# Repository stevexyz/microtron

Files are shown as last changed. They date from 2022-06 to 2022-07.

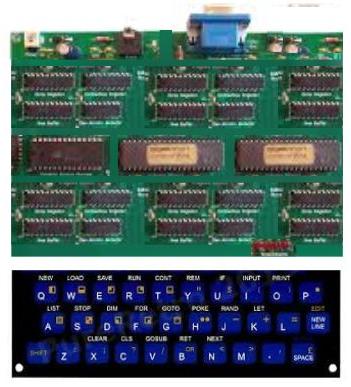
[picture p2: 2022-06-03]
microtron/microtron.jpg

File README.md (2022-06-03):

This is a fork of gigatron that is trying to minimize even more the number of components required.

Original project by Marcel van Kervinck and Walter Belgers can be found at https://gigatron.io

Discussion about microtron can be found at https://forum.gigatron.io/viewtopic.php?t=255

Schematic files are edited with KiCAD 6.

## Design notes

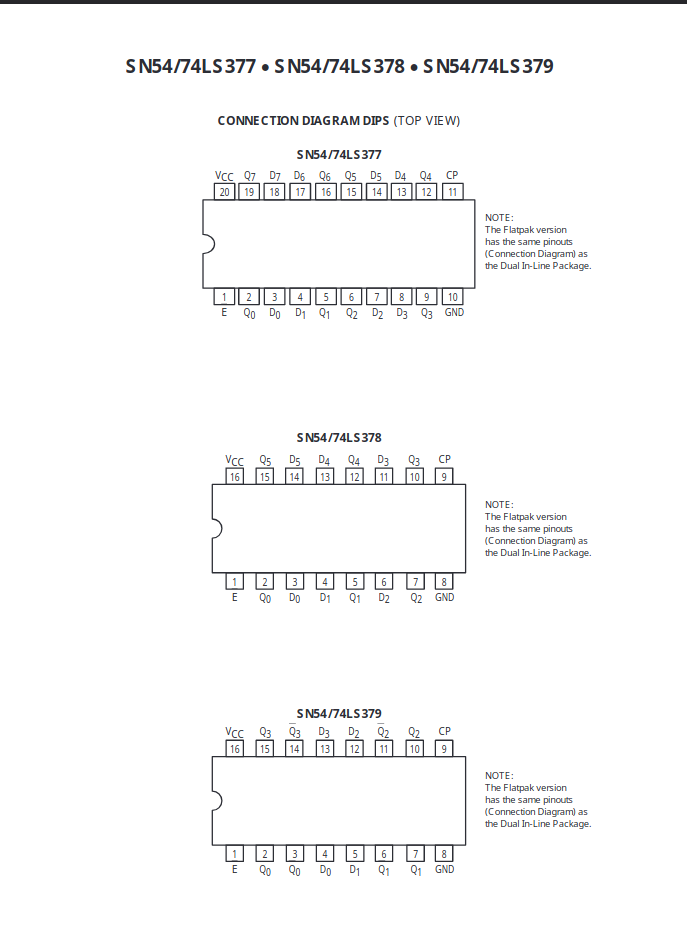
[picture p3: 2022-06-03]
datasheets/74ls377 8bit FF b.png

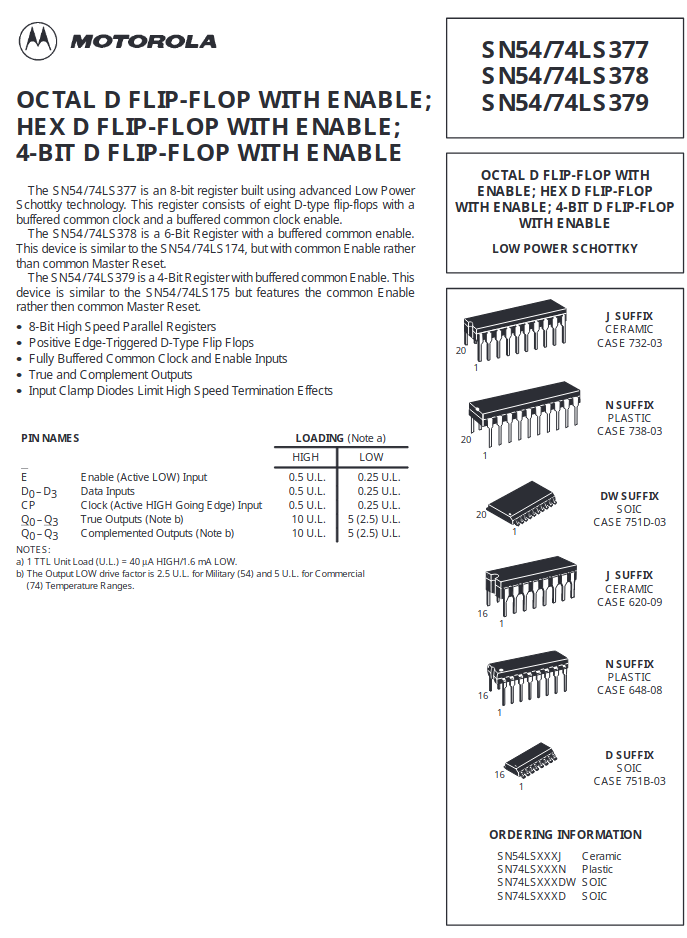
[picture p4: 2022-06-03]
datasheets/74ls377 8bit FF a.png

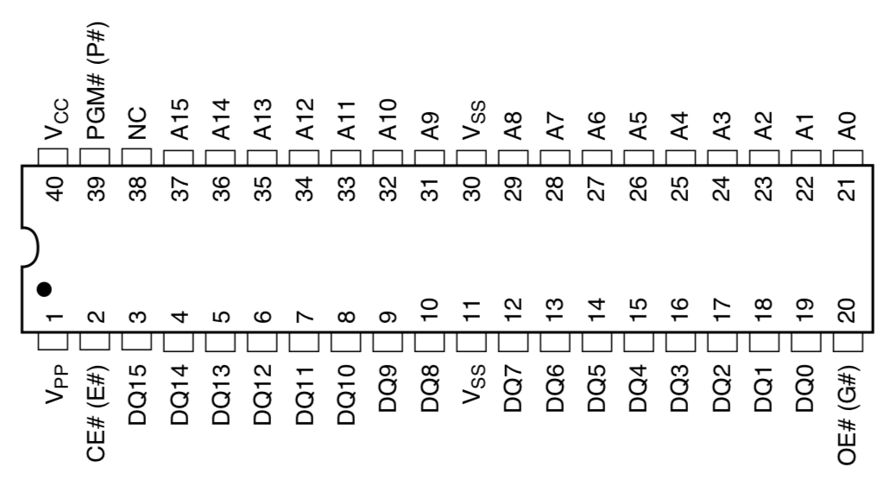
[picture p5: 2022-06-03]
datasheets/27c1024.png

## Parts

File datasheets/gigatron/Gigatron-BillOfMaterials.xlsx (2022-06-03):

Gigatron Bill of Materials
https://gigatron.io/
Copyright © 2020 Walter Belgers
This Gigatron Bill of Materials is provided "as-is"
and licensed under CC BY-SA 4.0.
To view a copy of this license, visit
https://creativecommons.org/licenses/by-sa/4.0
 |  |  |  |  |  | TTL microcomputer
Function/module | Description | Part/value | On PCB | Per kit | Part URL (e.g.)
Clock | 47pF ceramic disc capacitor, radial | Code 47 | C1-C3 | 3 | https://www.digikey.nl/product-detail/en/vishay-bc-components/K470J15C0GF5TL2/BC1009CT-ND/286631
Power | 220uF polarized radial input cap | Panasonic EEU-FC1E221 | C4 | 1 | https://nl.farnell.com/panasonic/eeu-fc1e221/cap-220-f-25v-20/dp/9692142
Power, Audio | 100nF ceramic disc | Code 104 | C5-C44 | 40 | https://www.digikey.nl/product-detail/en/vishay-bc-components/K104K10X7RF5UH5/BC2665CT-ND/2356879
Power | Zener diode 5.6V/5W | 1N5339B, DO-15 | D1 | 1 | https://nl.mouser.com/ProductDetail/Micro-Commercial-Components-MCC/1N5339B-TP
Power, Blinkenlights | LED (red) | 1.8V, 2mA, 3.15mm | D2, D5-D8 | 5 | https://www.digikey.com/product-detail/en/everlight-electronics-co-ltd/HLMP1700C6A0/1080-1048-1-ND/2675539
Control unit | Signaling diode | 1N60P or BAT42 compatible, DO-35 | D3-D4,D9-D36 | 30 | https://nl.mouser.com/ProductDetail/Vishay-Semiconductors/BAT42-TR
Power | Multifuse 60V/0.75A/180mΩ | MF-R075-ND | F1 | 1 | https://www.digikey.nl/product-detail/en/bourns-inc/MF-R075/MF-R075-ND/259967
Power | Mini-USB receptacle | 54819-0519 | J1 | 1 | http://nl.farnell.com/molex/54819-0519/mini-usb-2-0-otg-type-b-rcpt-th/dp/9786465
Audio | 3.5 mm audio jack | SJ-352{345}N | J2 | 1 | https://www.digikey.nl/product-detail/en/cui-inc/SJ1-3523N/CP1-3523N-ND/738689
Video | 15pin D-SUB female receptacle | L77HDE15SD1CH4R | J3 | 1 | http://uk.farnell.com/amphenol/l77hde15sd1ch4r/connector-hd-d-sub-rcpt-15pos/dp/2401183?MER=sy-me-pd-mi-alte
Game controller | 9pin D-SUB male receptacle | 5747840-3 | J4 | 1 | https://www.digikey.nl/product-detail/en/te-connectivity-amp-connectors/5747840-3/A32091-ND/808646
Clock | Feedback resistor | 1M | R1 | 1 | https://www.digikey.nl/product-detail/en/stackpole-electronics-inc/CF14JT1M00/CF14JT1M00CT-ND/1830423
Clock | Damping resistor | 1k | R2 | 1 | https://www.digikey.nl/product-detail/en/stackpole-electronics-inc/CF14JT1K00/CF14JT1K00CT-ND/1830350
Power, Control unit, Audio, Input | Resistor 2.2kΩ | 2.2k | R3,R6-R7,R10,R19 | 5 | https://www.digikey.nl/product-detail/en/stackpole-electronics-inc/CF14JT2K20/CF14JT2K20CT-ND/1830358
Controll unit, Blinkenlights | 5-pin resistor array, 2.2kΩ | 4605X-101-222LF | R4-R5,R8 | 3 | https://nl.mouser.com/ProductDetail/Bourns/4605X-101-222LF
Audio | 6-pin R2R netwerk, 10kΩ | 4606X-R2R-103LF | R9 | 1 | https://nl.mouser.com/ProductDetail/Bourns/4606X-R2R-103LF/
Video | DAC resistor | 1.5k | R11,R13,R15 | 3 | https://www.digikey.nl/product-detail/en/stackpole-electronics-inc/CF14JT1K50/CF14JT1K50CT-ND/1830354
Video | DAC resistor | 750 | R12,R14,R16 | 3 | https://www.digikey.nl/product-detail/en/stackpole-electronics-inc/CF14JT750R/CF14JT750RCT-ND/1830347
Video | Terminator HS/VS lines | 68 | R17-R18 | 2 | https://www.digikey.nl/product-detail/en/stackpole-electronics-inc/CF14JT68R0/CF14JT68R0CT-ND/1830323
Clock | Hex inverter (74HCT) | 74HCT04 | U1 | 1 | http://eu.mouser.com/ProductDetail/Texas-Instruments/SN74HCT04N/
Power | Supervisory circuit. Power-on Reset | MCP100-450DI/TO | U2 | 1 | https://www.digikey.nl/products/en?keywords=MCP100-450DI
Program Counter, X register | 4-bit presettable counter '161/'163 | 74HCT161 | U3-U6,U29-U30 | 6 | https://nl.mouser.com/Search/ProductDetail.aspx
Program ROM | EPROM 1Mb (64Kx16) | 27C1024, ≤150ns | U7 | 1 | https://nl.mouser.com/ProductDetail/Microchip-Technology-Atmel/AT27C1024-70PU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
IR,D,XOUT registers | 8-bit D-type register | 74HCT273 | U8-U9,U38 | 3 | https://nl.mouser.com/ProductDetail/Texas-Instruments/SN74HCT273N/
Databus en input | Octal bus driver non-inv | 74HCT244 | U10,U28 | 2 | https://nl.mouser.com/ProductDetail/Texas-Instruments/SN74HCT244N
Control unit | Dual 2-to-4 decoder | 74HCT139 | U11 | 1 | https://nl.farnell.com/texas-instruments/sn74hct139n/logic-dual-2to4-decod-demux-16dip/dp/3119925
Control unit, ALU | Dual 4-to-1 multiplexer | 74HCT153 | U12,U17-U24 | 9 | https://nl.mouser.com/ProductDetail/Texas-Instruments/CD74HCT153E/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
Control unit | 3-to-8 decoder | 74HCT138 | U13-U14 | 2 | https://nl.farnell.com/texas-instruments/sn74hct138n/ic-decoder-demux/dp/3119923?ost=74HCT138
Control unit | Octal inverting buffer | 74HCT240 | U15 | 1 | https://nl.farnell.com/texas-instruments/sn74hct240n/octal-buffer-line-driver-74hct240/dp/3119513
Control unit | Quad 2-input OR | 74HCT32 | U16 | 1 | https://nl.mouser.com/ProductDetail/Texas-Instruments/CD74HCT32EE4
ALU | 4-bit adder | 74HCT283 | U25-U26 | 2 | https://nl.mouser.com/ProductDetail/Texas-Instruments/CD74HCT283E/
AC, OUT and Y registers | Octal D-type flip-flops with common enable | 74HCT377 | U27,U31,U37 | 3 | https://www.digikey.nl/product-detail/en/texas-instruments/SN74HCT377N/296-8417-5-ND/376829
Address unit | Quad 2-to-1 line data selector | 74HCT157 | U32-U35 | 4 | https://www.digikey.nl/product-detail/en/texas-instruments/SN74HCT157N/296-8397-5-ND/376831
Data RAM | SRAM 32k x 8, 55ns | 62256 | U36 | 1 | http://nl.farnell.com/lyontek/ly62256pl-55lli/sram-256k-32kx8-2-7-5-5v-28pdip/dp/2253656?ost=LY62256PL-55LLI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
Input register | 8-bit shift register with 3-state output | 74HC595 | U39 | 1 | http://eu.mouser.com/ProductDetail/Texas-Instruments/SN74HC595N/
Clock | 6.25MHz/30pF crystal | MP062-E | Y1 | 1 | http://eu.mouser.com/Search/ProductDetail.aspx?R=MP062-Evirtualkey67110000virtualkey774-MP062-E
Interconnect | Printed Circuit Board (PCB) | green, lead-free HASL | - | 1 | your favourite PCB manufacturer
Power | USB cable | AWG28 | - | 1 | https://nl.mouser.com/ProductDetail/562-3021055-03
Program ROM | UV protection label | 25.4mm x 10mm | - | 1 | https://uk.farnell.com/te-connectivity/12100/label-eprom-pcb-pk500/dp/463802
IC sockets | IC socket | 40-pin DIP | - | 1 | https://www.digikey.nl/product-detail/en/on-shore-technology-inc/ED40DT/ED3048-5-ND/4147604
IC sockets | IC socket | 28-pin DIP | - | 1 | https://www.digikey.nl/product-detail/en/assmann-wsw-components/AR-28-HZL-TT/AE10017-ND/821771
Game controller | Prefab gamepad, famicom clone | DB9 serial | - | 1 | https://nl.aliexpress.com/item/32819985527.html
Enclosure | Wooden casing with plexiglass |  | - | 1 | custom made, no longer available
Enclosure | Little rubber feet (bumpons) | SJ-5302 (7.9mm) | - | 8 | https://nl.mouser.com/ProductDetail/3M-Electronic-Specialty/SJ-5302-CLEAR?qs=sGAEpiMZZMvlOED0T0kTWjxHiH3P5SU9
Manual | Full-colour paper manual | Wire-O, plastic cover | - | 1 | local copy shop
Pluggy McPlugface | Printed Circuit Board (PCB) | green, lead-free HASL | - | 1 | your favourite PCB manufacturer
Pluggy McPlugface | PS/2 receptacle | mini-DIN 6 pins | J1 | 1 | https://nl.mouser.com/ProductDetail/Kycon/KMDGX-6S-AS
Pluggy McPlugface | 9pin D-SUB female receptacle | L77SDE09SOL2 | J2 | 1 | https://nl.mouser.com/ProductDetail/523-L77SDE09SOL2
Pluggy McPlugface | Microcontroller | ATtiny85 DIP-8 | U1 | 1 | http://www.mouser.com/ProductDetail/microchip/attiny85-20pu/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
Pluggy McPlugface | IC socket | 8-pin DIP | - | 1 | http://www.mouser.com/ProductDetail/mill-max/110-47-308-41-001000/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
EPROM content | https://github.com/kervinck/gigatron-rom
ATtiny content | https://github.com/kervinck/gigatron-rom/tree/master/Utils/BabelFish
Assembly manual | https://gigatron.io/manual
Main PCB design files | https://gigatron.io/pcb
Pluggy PCB design files | https://gigatron.io/pluggy
20200623

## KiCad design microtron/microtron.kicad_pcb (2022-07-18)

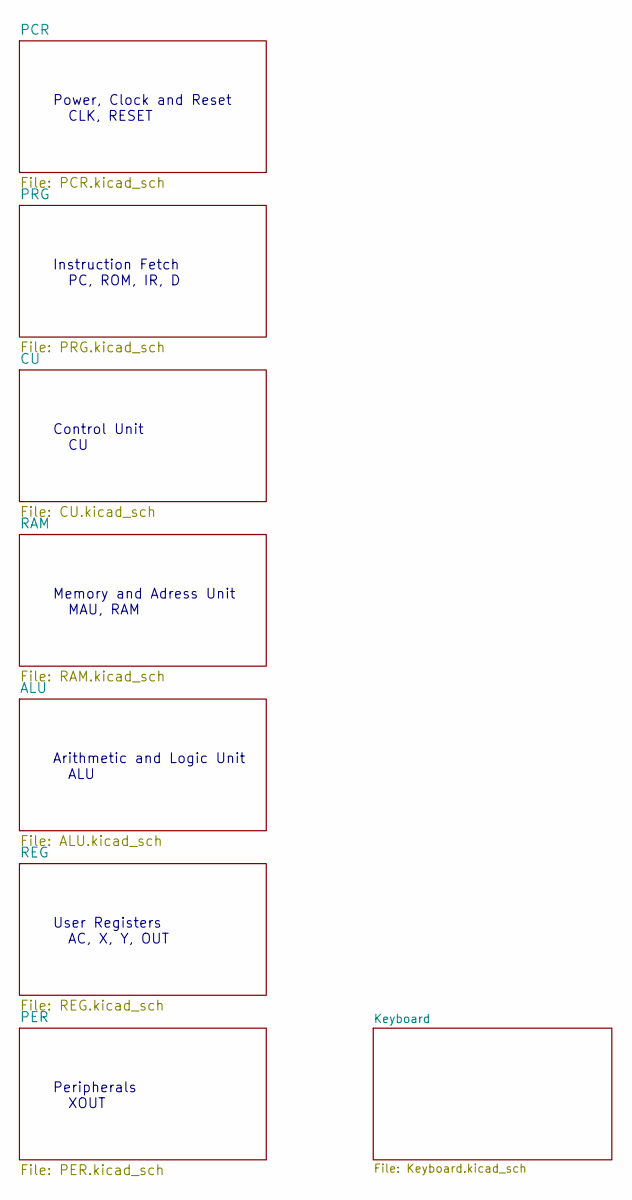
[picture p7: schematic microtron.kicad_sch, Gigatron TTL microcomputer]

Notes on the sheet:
Control Unit CU
Instruction Fetch PC, ROM, IR, D
Arithmetic and Logic Unit ALU
Memory and Adress Unit MAU, RAM
User Registers AC, X, Y, OUT
Peripherals XOUT
Power, Clock and Reset CLK, RESET

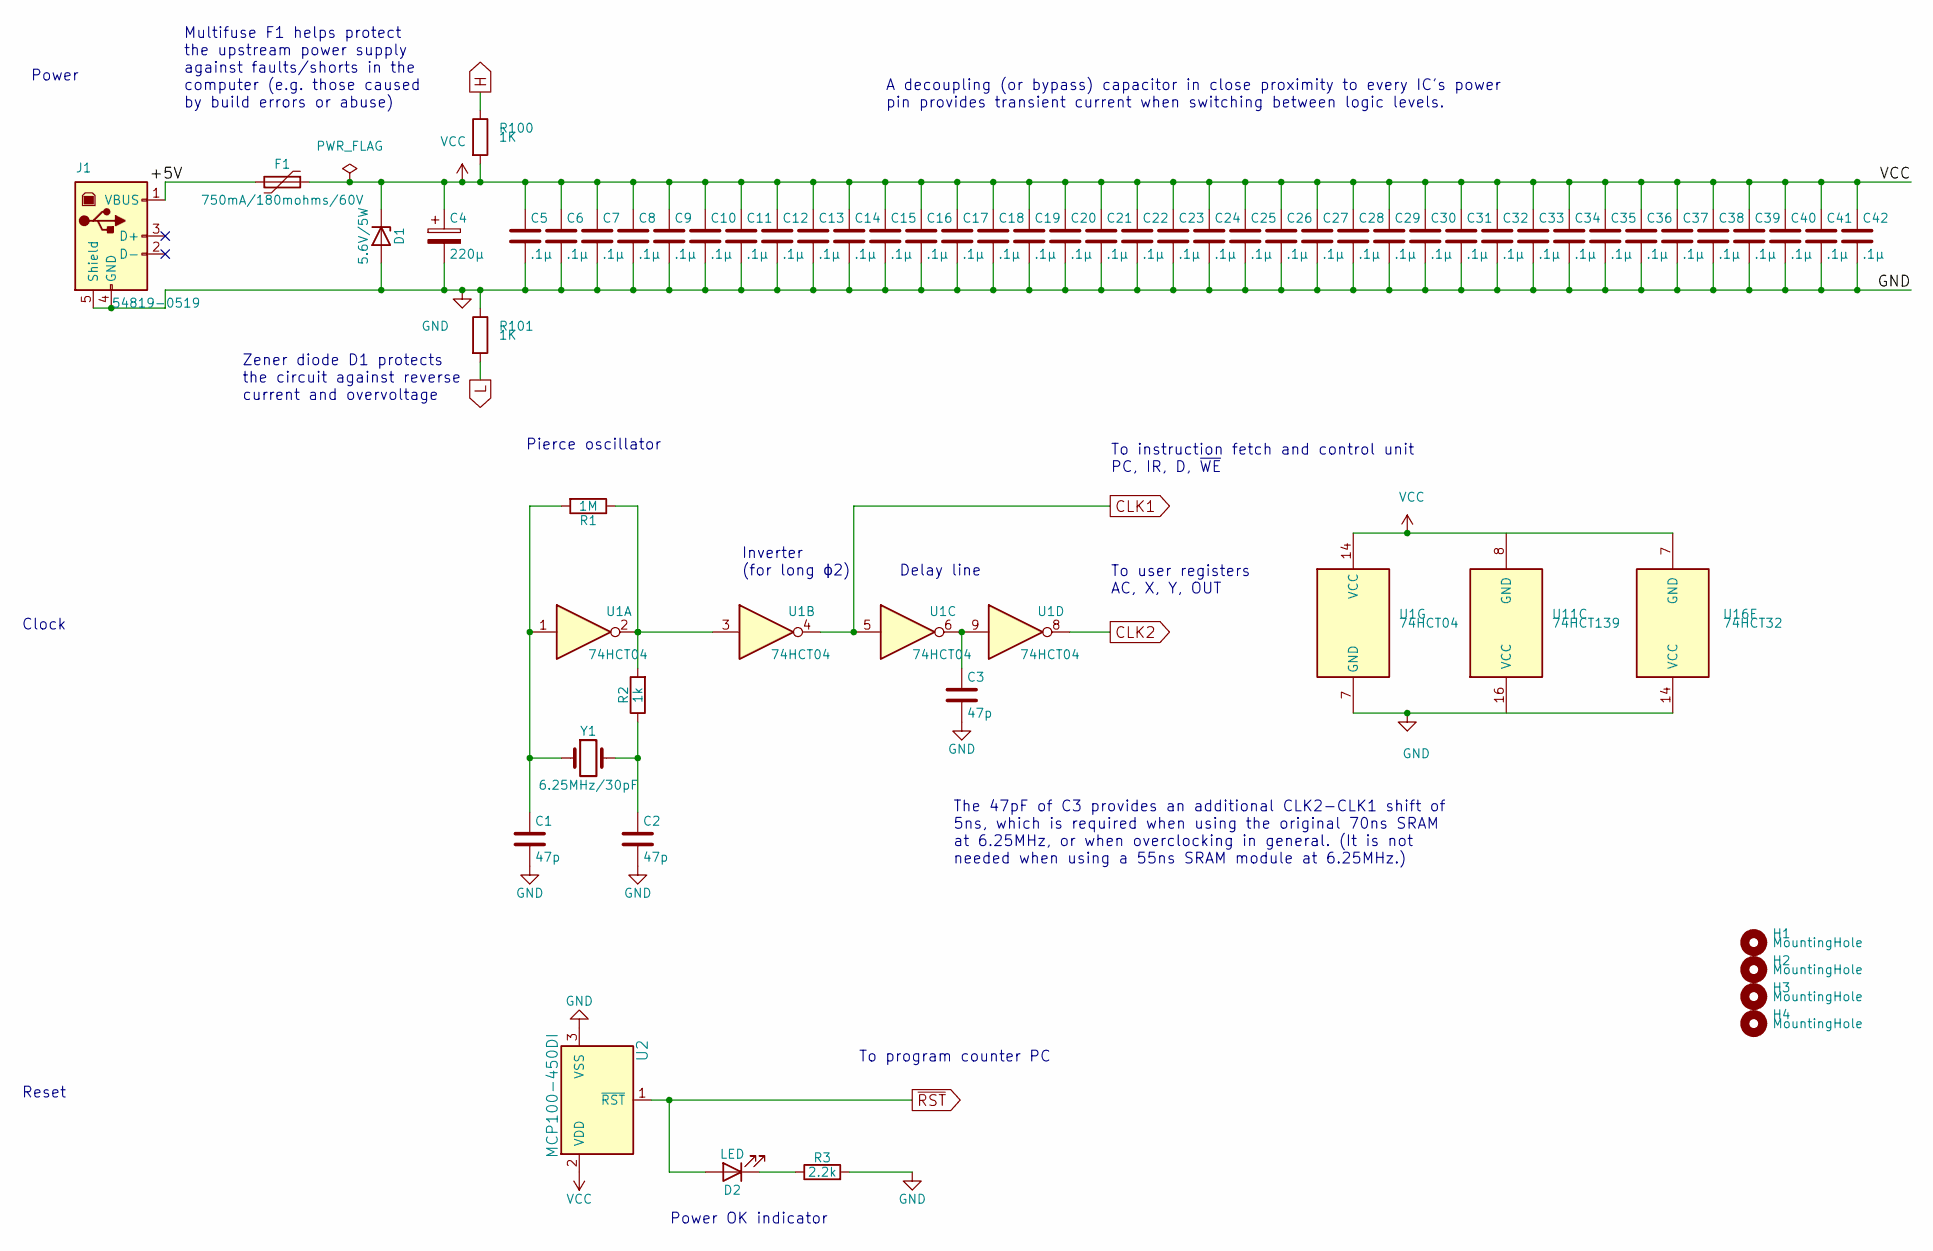
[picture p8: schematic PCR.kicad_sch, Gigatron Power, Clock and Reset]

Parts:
C1, C2, C3: 47p; C_Disc_D3.0mm_W2.0mm_P2.50mm
C4: 220µ; CP_Radial_D8.0mm_P3.50mm
C5, C6, C7, C8, C9, C10, C11, C12, C13, C14, C15, C16, C17, C18, C19, C20, C21, C22, C23, C24, C25, C26, C27, C28, C29, C30, C31, C32, C33, C34, C35, C36, C37, C38, C39, C40, C41, C42: .1µ; C_Disc_D4.3mm_W1.9mm_P5.00mm
D1: 5.6V/5W; D_DO-15_P12.70mm_Horizontal
D2: LED; LED_D3.0mm
F1: 750mA/180mohms/60V; Fuse_Littelfuse_395Series
H1, H2, H3, H4: MountingHole; MountingHole_2.7mm_M2.5
J1: 54819-0519; USB_Micro-B_Wuerth_629105150521
R1: 1M; R_Axial_DIN0207_L6.3mm_D2.5mm_P10.16mm_Horizontal
R2: 1k; R_Axial_DIN0207_L6.3mm_D2.5mm_P10.16mm_Horizontal
R3: 2.2k; R_Axial_DIN0207_L6.3mm_D2.5mm_P10.16mm_Horizontal
R100, R101: 1K; R_Axial_DIN0204_L3.6mm_D1.6mm_P1.90mm_Vertical
U1: 74HCT04; DIP-14_W7.62mm
U2: MCP100-450DI; TO-92L_Inline_Wide
U11: 74HCT139; DIP-16_W7.62mm
U16: 74HCT32; DIP-14_W7.62mm
Y1: 6.25MHz/30pF; Crystal_HC49-U_Vertical

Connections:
/PCR/+5V: F1.2, J1.1 (VBUS)
CLK1: U1.4, U1.5; also elsewhere on the board
CLK2: U1.8; also elsewhere on the board
GND: C1.2, C2.2, C3.2, C4.2, C5.2, C6.2, C7.2, C8.2, C9.2, C10.2, C11.2, C12.2, C13.2, C14.2, C15.2, C16.2, C17.2, C18.2, C19.2, C20.2, C21.2, C22.2, C23.2, C24.2, C25.2, C26.2, C27.2, C28.2, C29.2, C30.2, C31.2, C32.2, C33.2, C34.2, C35.2, C36.2, C37.2, C38.2, C39.2, C40.2, C41.2, C42.2, D1.2 (A), J1.4 (GND), J1.5 (Shield), R3.2, R101.1, U1.7 (GND), U2.3 (VSS), U16.14 (VCC); also elsewhere on the board
H: R100.1; also elsewhere on the board
L: R101.2; also elsewhere on the board
unnamed: C1.1, R1.2, U1.1, Y1.1
unnamed: C2.1, R2.1, Y1.2
unnamed: C3.1, U1.6, U1.9
unnamed: D2.1 (K), R3.1
unnamed: R1.1, R2.2, U1.2
VCC: C4.1, C5.1, C6.1, C7.1, C8.1, C9.1, C10.1, C11.1, C12.1, C13.1, C14.1, C15.1, C16.1, C17.1, C18.1, C19.1, C20.1, C21.1, C22.1, C23.1, C24.1, C25.1, C26.1, C27.1, C28.1, C29.1, C30.1, C31.1, C32.1, C33.1, C34.1, C35.1, C36.1, C37.1, C38.1, C39.1, C40.1, C41.1, C42.1, D1.1 (K), F1.1, R100.2, U1.14 (VCC), U2.2 (VDD), U16.7 (GND); also elsewhere on the board
~RST: D2.2 (A), U2.1 (~RST); also elsewhere on the board

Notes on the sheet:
To user registers AC, X, Y, OUT
Zener diode D1 protects the circuit against reverse current and overvoltage
Clock
The 47pF of C3 provides an additional CLK2-CLK1 shift of 5ns, which is required when using the original 70ns SRAM at 6.25MHz, or when overclocking in general. (It is not needed when using a 55ns SRAM module at 6.25MHz.)
Multifuse F1 helps protect the upstream power supply against faults/shorts in the computer (e.g. those caused by build errors or abuse)
To instruction fetch and control unit PC, IR, D, ~{WE}
A decoupling (or bypass) capacitor in close proximity to every IC's power pin provides transient current when switching between logic levels.
Power OK indicator
Power
Inverter (for long ɸ2)
Pierce oscillator
Reset
Delay line
To program counter PC

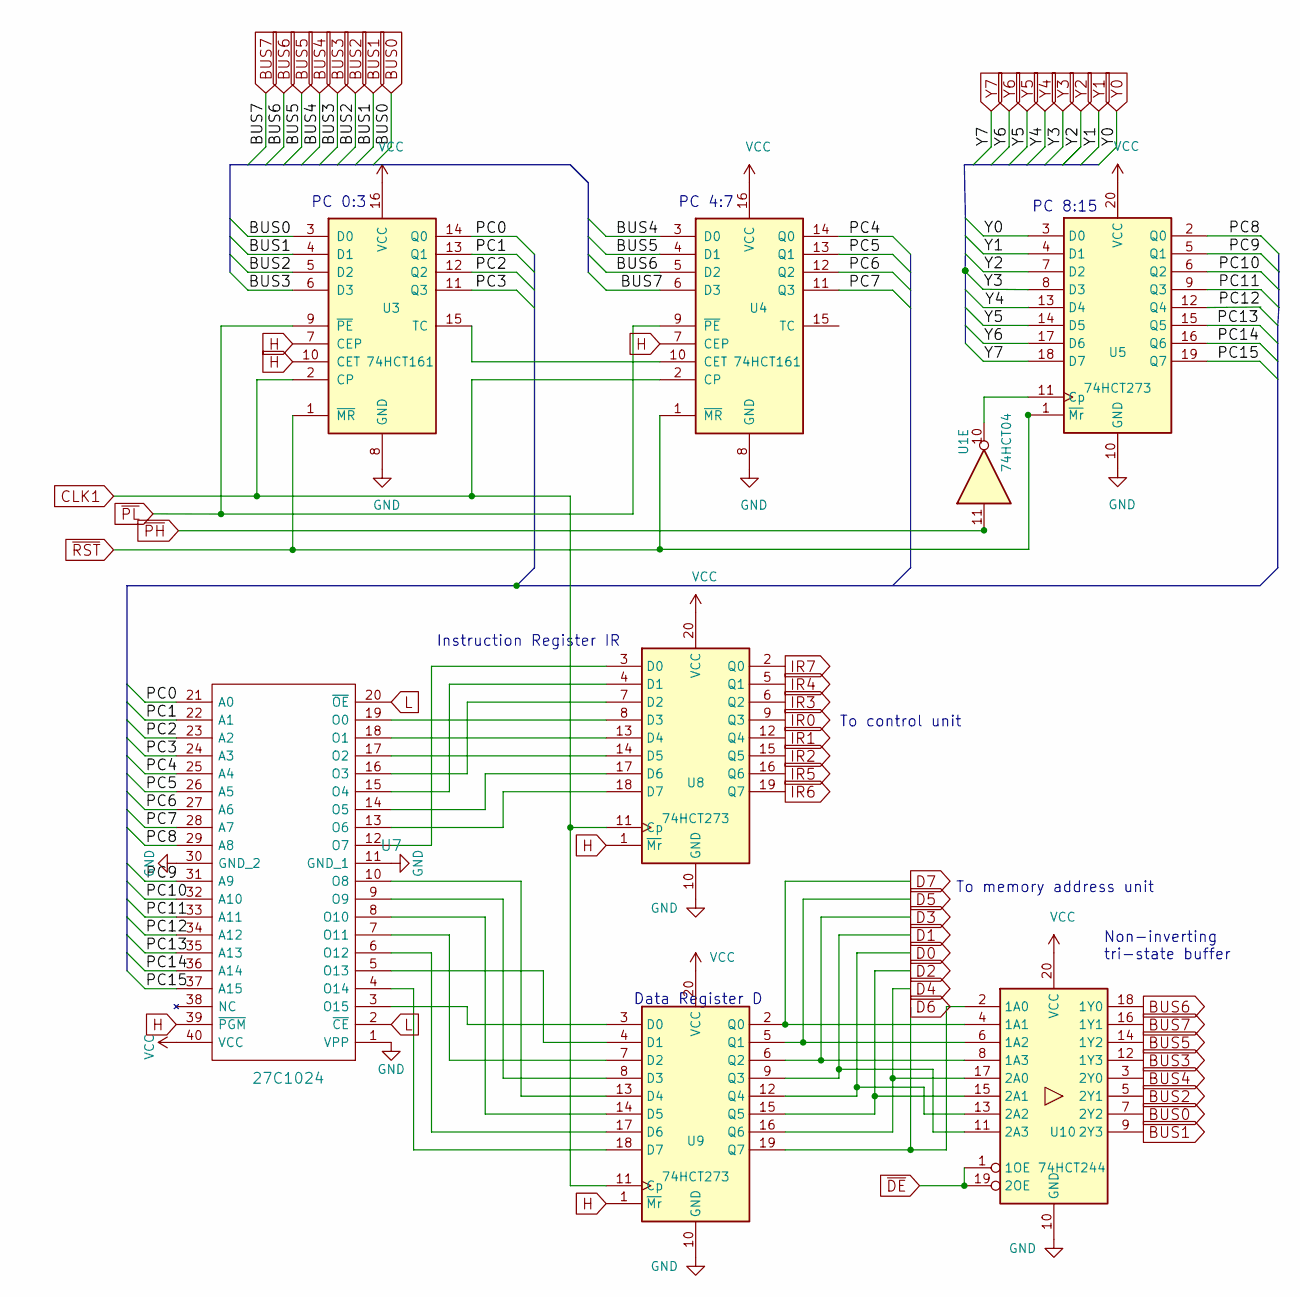
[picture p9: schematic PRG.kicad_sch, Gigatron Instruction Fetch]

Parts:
U1: 74HCT04; DIP-14_W7.62mm
U3, U4: 74HCT161; DIP-16_W7.62mm
U5, U8, U9: 74HCT273; DIP-20_W7.62mm
U7: 27C1024; DIP-40_W15.24mm
U10: 74HCT244; DIP-20_W7.62mm

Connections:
/PRG/PC0: U3.14 (Q0), U7.21 (A0)
/PRG/PC1: U3.13 (Q1), U7.22 (A1)
/PRG/PC2: U3.12 (Q2), U7.23 (A2)
/PRG/PC3: U3.11 (Q3), U7.24 (A3)
/PRG/PC4: U4.14 (Q0), U7.25 (A4)
/PRG/PC5: U4.13 (Q1), U7.26 (A5)
/PRG/PC6: U4.12 (Q2), U7.27 (A6)
/PRG/PC7: U4.11 (Q3), U7.28 (A7)
/PRG/PC8: U5.2 (Q0), U7.29 (A8)
/PRG/PC9: U5.5 (Q1), U7.31 (A9)
/PRG/PC10: U5.6 (Q2), U7.32 (A10)
/PRG/PC11: U5.9 (Q3), U7.33 (A11)
/PRG/PC12: U5.12 (Q4), U7.34 (A12)
/PRG/PC13: U5.15 (Q5), U7.35 (A13)
/PRG/PC14: U5.16 (Q6), U7.36 (A14)
/PRG/PC15: U5.19 (Q7), U7.37 (A15)
BUS0: U3.3 (D0), U10.7 (2Y2); also elsewhere on the board
BUS1: U3.4 (D1), U10.9 (2Y3); also elsewhere on the board
BUS2: U3.5 (D2), U10.5 (2Y1); also elsewhere on the board
BUS3: U3.6 (D3), U10.12 (1Y3); also elsewhere on the board
BUS4: U4.3 (D0), U10.3 (2Y0); also elsewhere on the board
BUS5: U4.4 (D1), U10.14 (1Y2); also elsewhere on the board
BUS6: U4.5 (D2), U10.18 (1Y0); also elsewhere on the board
BUS7: U4.6 (D3), U10.16 (1Y1); also elsewhere on the board
CLK1: U3.2 (CP), U4.2 (CP), U8.11 (Cp), U9.11 (Cp); also elsewhere on the board
D0: U9.12 (Q4), U10.13 (2A2); also elsewhere on the board
D1: U9.9 (Q3), U10.11 (2A3); also elsewhere on the board
D2: U9.15 (Q5), U10.15 (2A1); also elsewhere on the board
D3: U9.6 (Q2), U10.8 (1A3); also elsewhere on the board
D4: U9.16 (Q6), U10.17 (2A0); also elsewhere on the board
D5: U9.5 (Q1), U10.6 (1A2); also elsewhere on the board
D6: U9.19 (Q7), U10.2 (1A0); also elsewhere on the board
D7: U9.2 (Q0), U10.4 (1A1); also elsewhere on the board
GND: U3.8 (GND), U4.8 (GND), U5.10 (GND), U7.1 (VPP), U7.11 (GND_1), U7.30 (GND_2), U8.10 (GND), U9.10 (GND), U10.10 (GND); also elsewhere on the board
H: U3.7 (CEP), U3.10 (CET), U4.7 (CEP), U7.39 (~PGM), U8.1 (~Mr), U9.1 (~Mr); also elsewhere on the board
IR0: U8.9 (Q3); also elsewhere on the board
IR1: U8.12 (Q4); also elsewhere on the board
IR2: U8.15 (Q5); also elsewhere on the board
IR3: U8.6 (Q2); also elsewhere on the board
IR4: U8.5 (Q1); also elsewhere on the board
IR5: U8.16 (Q6); also elsewhere on the board
IR6: U8.19 (Q7); also elsewhere on the board
IR7: U8.2 (Q0); also elsewhere on the board
L: U7.2 (~CE), U7.20 (~OE); also elsewhere on the board
unnamed: U1.10, U5.11 (Cp)
unnamed: U3.15 (TC), U4.10 (CET)
unnamed: U7.3 (O15), U9.3 (D0)
unnamed: U7.4 (O14), U9.18 (D7)
unnamed: U7.5 (O13), U9.4 (D1)
unnamed: U7.6 (O12), U9.17 (D6)
unnamed: U7.7 (O11), U9.7 (D2)
unnamed: U7.8 (O10), U9.14 (D5)
unnamed: U7.9 (O9), U9.8 (D3)
unnamed: U7.10 (O8), U9.13 (D4)
unnamed: U7.12 (O7), U8.3 (D0)
unnamed: U7.13 (O6), U8.18 (D7)
unnamed: U7.14 (O5), U8.17 (D6)
unnamed: U7.15 (O4), U8.4 (D1)
unnamed: U7.16 (O3), U8.7 (D2)
unnamed: U7.17 (O2), U8.14 (D5)
unnamed: U7.18 (O1), U8.13 (D4)
unnamed: U7.19 (O0), U8.8 (D3)
VCC: U3.16 (VCC), U4.16 (VCC), U5.20 (VCC), U7.40 (VCC), U8.20 (VCC), U9.20 (VCC), U10.20 (VCC); also elsewhere on the board
Y0: U5.3 (D0); also elsewhere on the board
Y1: U5.4 (D1); also elsewhere on the board
Y2: U5.7 (D2); also elsewhere on the board
Y3: U5.8 (D3); also elsewhere on the board
Y4: U5.13 (D4); also elsewhere on the board
Y5: U5.14 (D5); also elsewhere on the board
Y6: U5.17 (D6); also elsewhere on the board
Y7: U5.18 (D7); also elsewhere on the board
~DE: U10.1 (1OE), U10.19 (2OE); also elsewhere on the board
~PL: U3.9 (~PE), U4.9 (~PE); also elsewhere on the board
~RST: U3.1 (~MR), U4.1 (~MR), U5.1 (~Mr); also elsewhere on the board

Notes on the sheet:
Data Register D
PC 0:3
To control unit
Non-inverting tri-state buffer
Instruction Register IR
PC 8:15
PC 4:7
To memory address unit

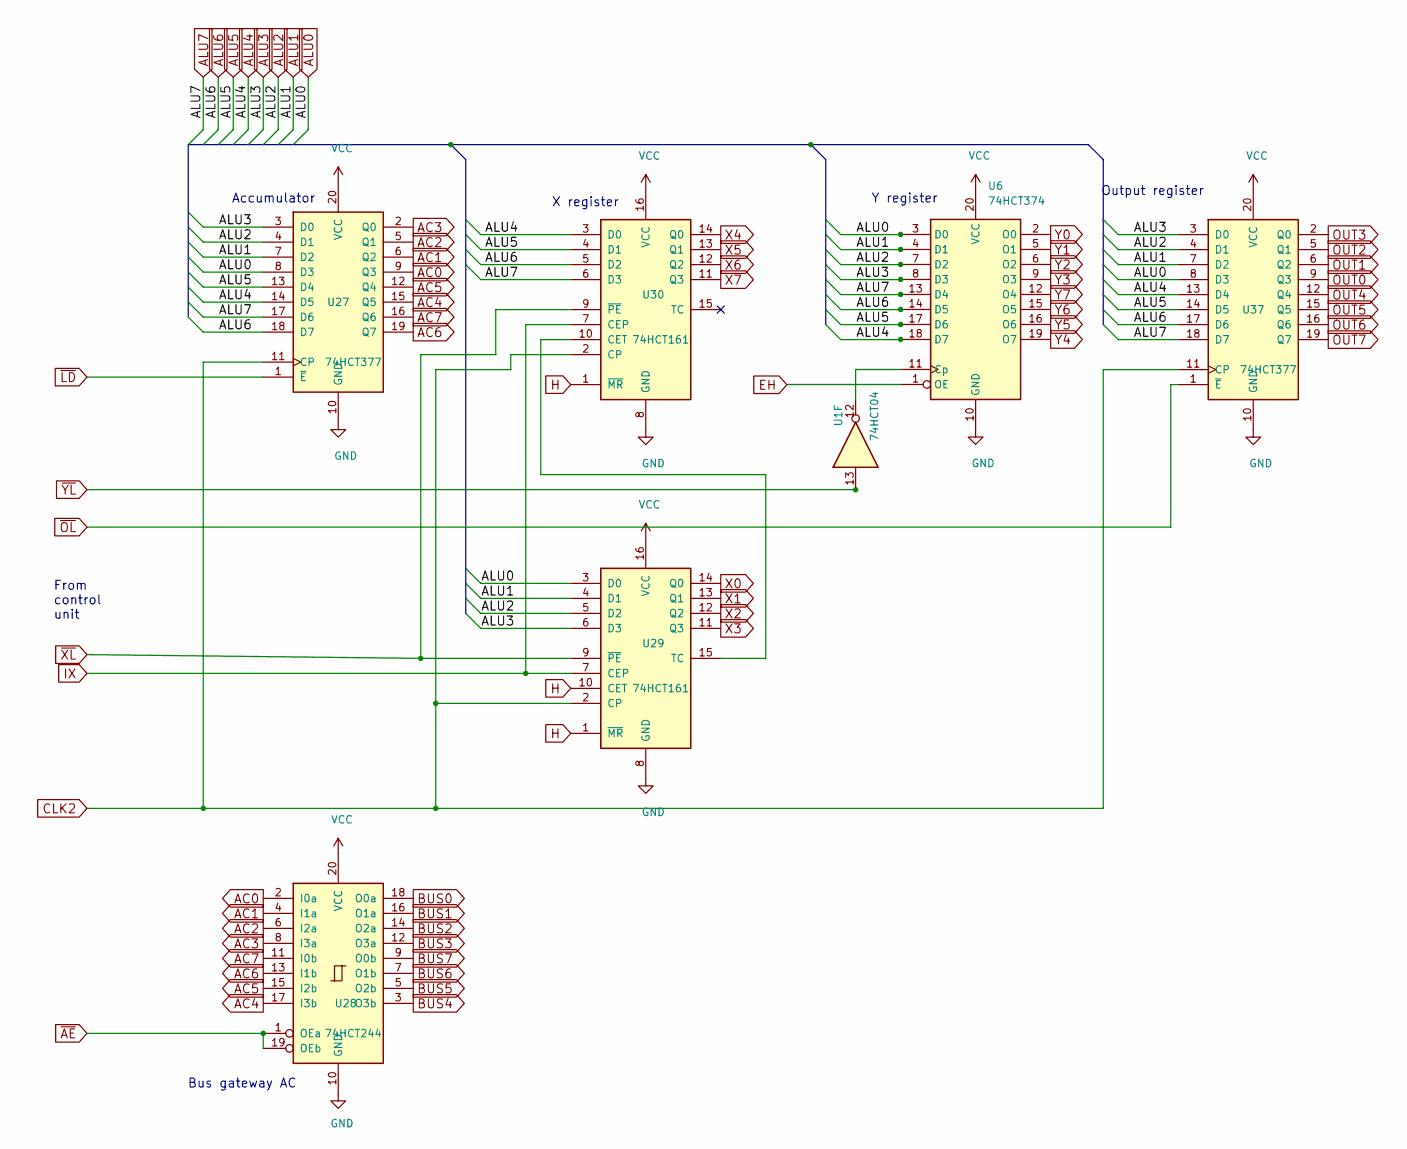
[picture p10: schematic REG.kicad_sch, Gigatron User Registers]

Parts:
U1: 74HCT04; DIP-14_W7.62mm
U6: 74HCT374; DIP-20_W7.62mm
U27, U37: 74HCT377; DIP-20_W7.62mm
U28: 74HCT244; DIP-20_W7.62mm
U29, U30: 74HCT161; DIP-16_W7.62mm

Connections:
AC0: U27.9 (Q3), U28.2 (I0a); also elsewhere on the board
AC1: U27.6 (Q2), U28.4 (I1a); also elsewhere on the board
AC2: U27.5 (Q1), U28.6 (I2a); also elsewhere on the board
AC3: U27.2 (Q0), U28.8 (I3a); also elsewhere on the board
AC4: U27.15 (Q5), U28.17 (I3b); also elsewhere on the board
AC5: U27.12 (Q4), U28.15 (I2b); also elsewhere on the board
AC6: U27.19 (Q7), U28.13 (I1b); also elsewhere on the board
AC7: U27.16 (Q6), U28.11 (I0b); also elsewhere on the board
ALU0: U27.8 (D3), U29.3 (D0), U37.8 (D3); also elsewhere on the board
ALU1: U27.7 (D2), U29.4 (D1), U37.7 (D2); also elsewhere on the board
ALU2: U27.4 (D1), U29.5 (D2), U37.4 (D1); also elsewhere on the board
ALU3: U27.3 (D0), U29.6 (D3), U37.3 (D0); also elsewhere on the board
ALU4: U27.14 (D5), U30.3 (D0), U37.13 (D4); also elsewhere on the board
ALU5: U27.13 (D4), U30.4 (D1), U37.14 (D5); also elsewhere on the board
ALU6: U27.18 (D7), U30.5 (D2), U37.17 (D6); also elsewhere on the board
ALU7: U27.17 (D6), U30.6 (D3), U37.18 (D7); also elsewhere on the board
BUS0: U28.18 (O0a); also elsewhere on the board
BUS1: U28.16 (O1a); also elsewhere on the board
BUS2: U28.14 (O2a); also elsewhere on the board
BUS3: U28.12 (O3a); also elsewhere on the board
BUS4: U28.3 (O3b); also elsewhere on the board
BUS5: U28.5 (O2b); also elsewhere on the board
BUS6: U28.7 (O1b); also elsewhere on the board
BUS7: U28.9 (O0b); also elsewhere on the board
CLK2: U27.11 (CP), U29.2 (CP), U30.2 (CP), U37.11 (CP); also elsewhere on the board
EH: U6.1 (OE); also elsewhere on the board
GND: U6.10 (GND), U27.10 (GND), U28.10 (GND), U29.8 (GND), U30.8 (GND), U37.10 (GND); also elsewhere on the board
H: U29.1 (~MR), U29.10 (CET), U30.1 (~MR); also elsewhere on the board
IX: U29.7 (CEP), U30.7 (CEP); also elsewhere on the board
unnamed: U1.12, U6.11 (Cp)
unnamed: U29.15 (TC), U30.10 (CET)
OUT0: U37.9 (Q3); also elsewhere on the board
OUT1: U37.6 (Q2); also elsewhere on the board
OUT2: U37.5 (Q1); also elsewhere on the board
OUT3: U37.2 (Q0); also elsewhere on the board
OUT4: U37.12 (Q4); also elsewhere on the board
OUT5: U37.15 (Q5); also elsewhere on the board
OUT6: U37.16 (Q6); also elsewhere on the board
OUT7: U37.19 (Q7); also elsewhere on the board
VCC: U6.20 (VCC), U27.20 (VCC), U28.20 (VCC), U29.16 (VCC), U30.16 (VCC), U37.20 (VCC); also elsewhere on the board
X0: U29.14 (Q0); also elsewhere on the board
X1: U29.13 (Q1); also elsewhere on the board
X2: U29.12 (Q2); also elsewhere on the board
X3: U29.11 (Q3); also elsewhere on the board
X4: U30.14 (Q0); also elsewhere on the board
X5: U30.13 (Q1); also elsewhere on the board
X6: U30.12 (Q2); also elsewhere on the board
X7: U30.11 (Q3); also elsewhere on the board
Y0: U6.2 (O0); also elsewhere on the board
Y1: U6.5 (O1); also elsewhere on the board
Y2: U6.6 (O2); also elsewhere on the board
Y3: U6.9 (O3); also elsewhere on the board
Y4: U6.19 (O7); also elsewhere on the board
Y5: U6.16 (O6); also elsewhere on the board
Y6: U6.15 (O5); also elsewhere on the board
Y7: U6.12 (O4); also elsewhere on the board
~AE: U28.1 (OEa), U28.19 (OEb); also elsewhere on the board
~LD: U27.1 (~E); also elsewhere on the board
~OL: U37.1 (~E); also elsewhere on the board
~XL: U29.9 (~PE), U30.9 (~PE); also elsewhere on the board

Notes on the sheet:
Accumulator
Output register
Bus gateway AC
X register
Y register
From control unit

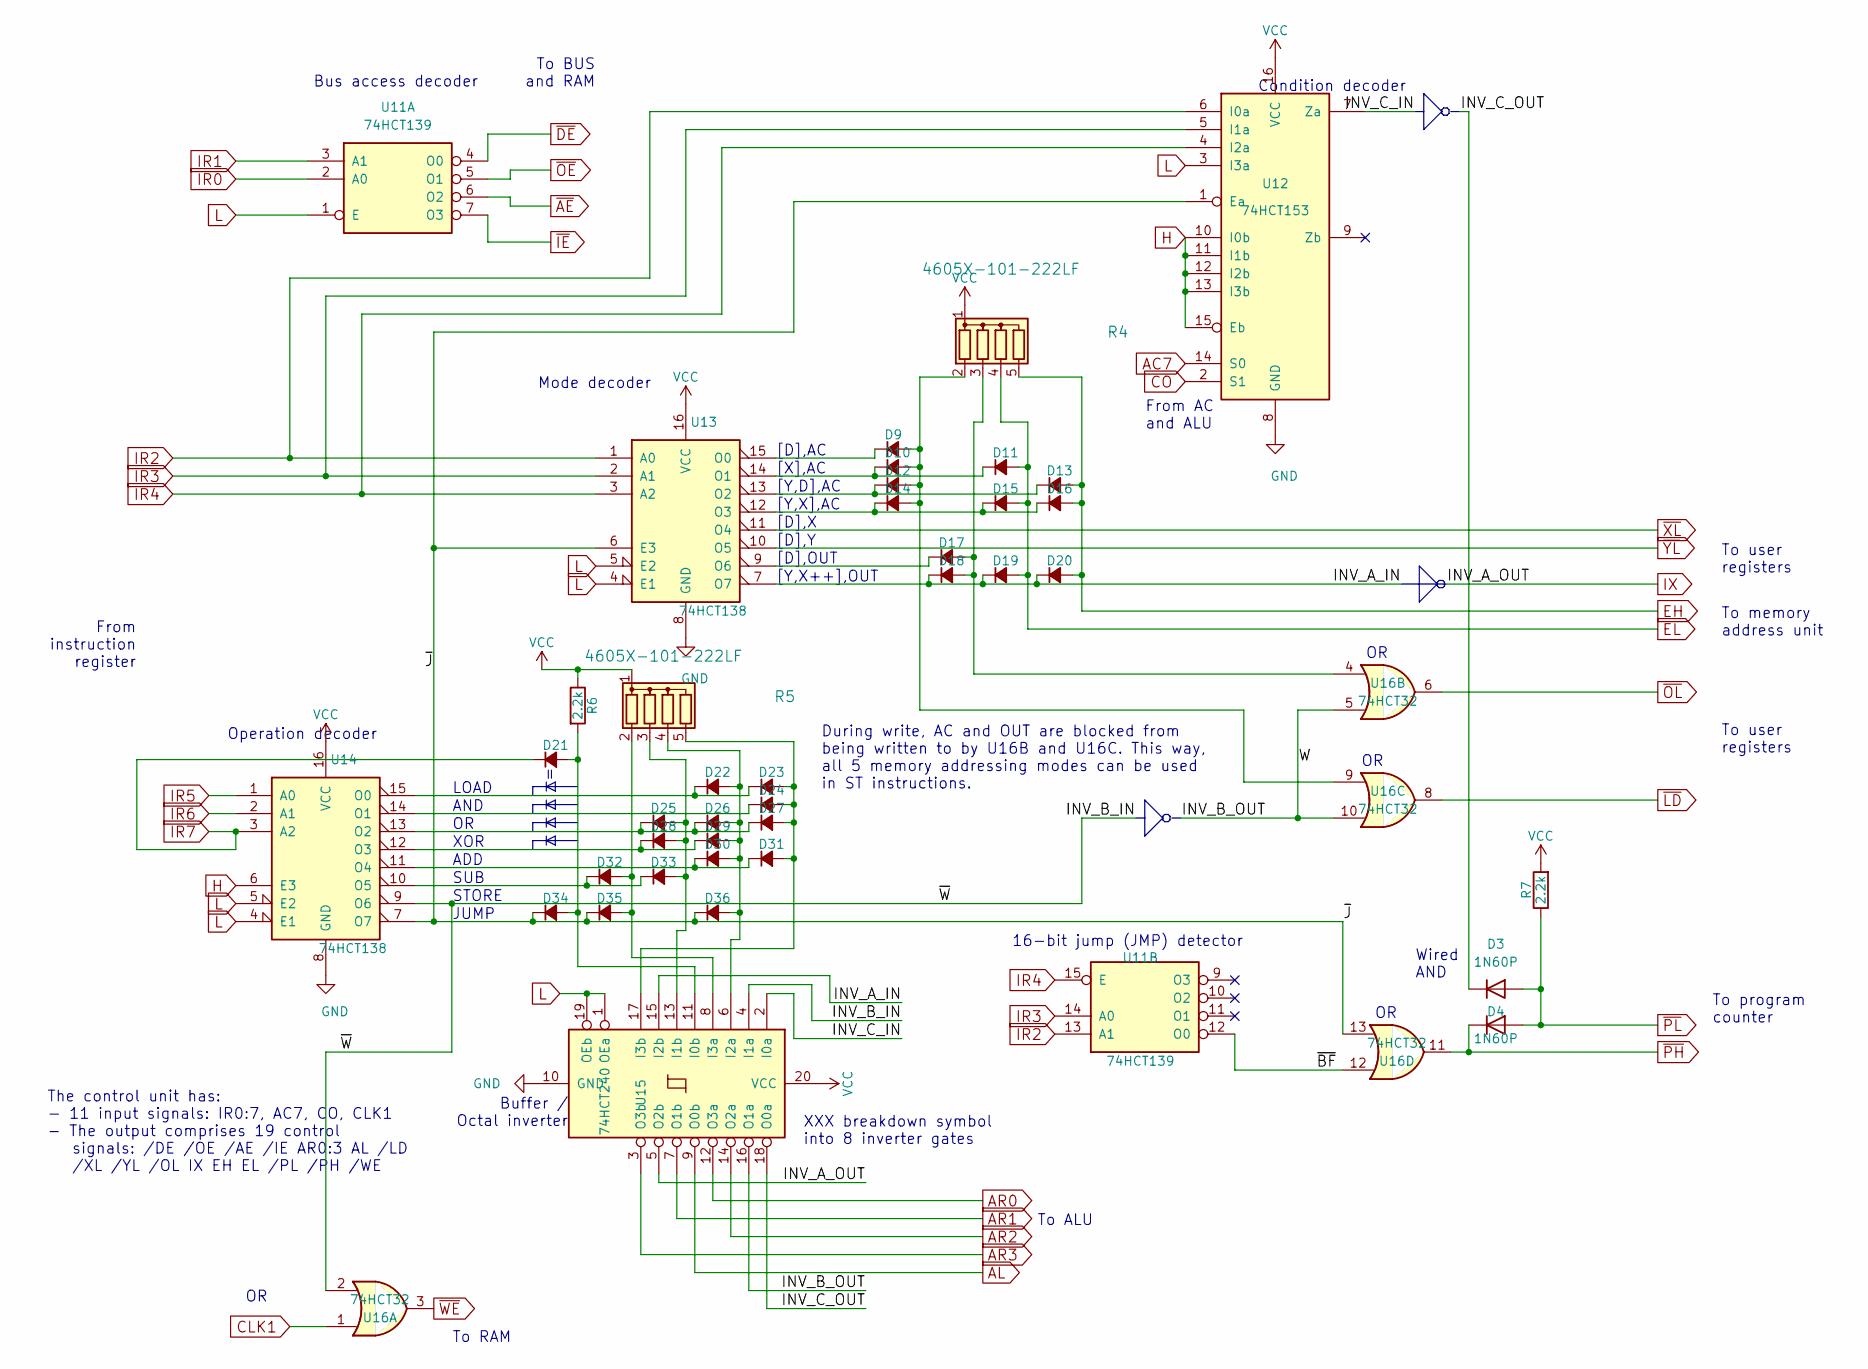
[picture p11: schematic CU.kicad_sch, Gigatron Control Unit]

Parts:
D3, D4: 1N60P; D_A-405_P7.62mm_Horizontal
D9, D10, D11, D12, D13, D14, D15, D16, D17, D18, D19, D20, D21, D22, D23, D24, D25, D26, D27, D28, D29, D30, D31, D32, D33, D34, D35, D36: 1N60P; D_A-405_P2.54mm_Vertical_KathodeUp
R4, R5: 4605X-101-222LF; R_Array_SIP5
R6, R7: 2.2k; R_Axial_DIN0207_L6.3mm_D2.5mm_P10.16mm_Horizontal
U11: 74HCT139; DIP-16_W7.62mm
U12: 74HCT153; DIP-16_W7.62mm
U13, U14: 74HCT138; DIP-16_W7.62mm
U15: 74HCT240; DIP-20_W7.62mm
U16: 74HCT32; DIP-14_W7.62mm

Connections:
/CU/INV_A_IN: D18.1 (K), D19.1 (K), D20.1 (K), U13.7 (O7), U15.15 (I2b)
/CU/INV_B_IN: U14.9 (O6), U15.4 (I1a), U16.2
/CU/INV_B_OUT: U15.16 (O1a), U16.5, U16.10
/CU/INV_C_IN: U12.7 (Za), U15.2 (I0a)
/CU/INV_C_OUT: D3.1 (K), U15.18 (O0a)
/CU/~BF: U11.12 (O0), U16.12
/CU/~J: D34.1 (K), D35.1 (K), D36.1 (K), U12.1 (Ea), U13.6 (E3), U14.7 (O7), U16.13
AC7: U12.14 (S0); also elsewhere on the board
AL: U15.9 (O0b); also elsewhere on the board
AR0: U15.12 (O3a); also elsewhere on the board
AR1: U15.7 (O1b); also elsewhere on the board
AR2: U15.14 (O2a); also elsewhere on the board
AR3: U15.3 (O3b); also elsewhere on the board
CLK1: U16.1; also elsewhere on the board
CO: U12.2 (S1); also elsewhere on the board
EH: D13.2 (A), D16.2 (A), D20.2 (A), R4.5 (R4); also elsewhere on the board
EL: D11.2 (A), D15.2 (A), D19.2 (A), R4.4 (R3); also elsewhere on the board
GND: U12.8 (GND), U13.8 (GND), U14.8 (GND), U15.10 (GND); also elsewhere on the board
H: U12.10 (I0b), U12.11 (I1b), U12.12 (I2b), U12.13 (I3b), U12.15 (Eb), U14.6 (E3); also elsewhere on the board
IR0: U11.2 (A0); also elsewhere on the board
IR1: U11.3 (A1); also elsewhere on the board
IR2: U11.13 (A1), U12.6 (I0a), U13.1 (A0); also elsewhere on the board
IR3: U11.14 (A0), U12.5 (I1a), U13.2 (A1); also elsewhere on the board
IR4: U11.15 (E), U12.4 (I2a), U13.3 (A2); also elsewhere on the board
IR5: U14.1 (A0); also elsewhere on the board
IR6: U14.2 (A1); also elsewhere on the board
IR7: D21.1 (K), U14.3 (A2); also elsewhere on the board
IX: U15.5 (O2b); also elsewhere on the board
L: U11.1 (E), U12.3 (I3a), U13.4 (E1), U13.5 (E2), U14.4 (E1), U14.5 (E2), U15.1 (OEa), U15.19 (OEb); also elsewhere on the board
unnamed: D9.1 (K), U13.15 (O0)
unnamed: D10.1 (K), D11.1 (K), U13.14 (O1)
unnamed: D9.2 (A), D10.2 (A), D12.2 (A), D14.2 (A), R4.2 (R1), U16.9
unnamed: D12.1 (K), D13.1 (K), U13.13 (O2)
unnamed: D14.1 (K), D15.1 (K), D16.1 (K), U13.12 (O3)
unnamed: D17.1 (K), U13.9 (O6)
unnamed: D17.2 (A), D18.2 (A), R4.3 (R2), U16.4
unnamed: D21.2 (A), D34.2 (A), R6.2, U15.11 (I0b)
unnamed: D22.1 (K), D23.1 (K), U14.15 (O0)
unnamed: D22.2 (A), D26.2 (A), D29.2 (A), D30.2 (A), D36.2 (A), R5.4 (R3), U15.6 (I2a)
unnamed: D23.2 (A), D24.2 (A), D27.2 (A), D31.2 (A), R5.5 (R4), U15.17 (I3b)
unnamed: D24.1 (K), U14.14 (O1)
unnamed: D25.1 (K), D26.1 (K), D27.1 (K), U14.13 (O2)
unnamed: D25.2 (A), D28.2 (A), D33.2 (A), R5.3 (R2), U15.13 (I1b)
unnamed: D28.1 (K), D29.1 (K), U14.12 (O3)
unnamed: D30.1 (K), D31.1 (K), U14.11 (O4)
unnamed: D32.1 (K), D33.1 (K), U14.10 (O5)
unnamed: D32.2 (A), D35.2 (A), R5.2 (R1), U15.8 (I3a)
VCC: R4.1 (common), R5.1 (common), R6.1, R7.2, U12.16 (VCC), U13.16 (VCC), U14.16 (VCC), U15.20 (VCC); also elsewhere on the board
~AE: U11.6 (O2); also elsewhere on the board
~DE: U11.4 (O0); also elsewhere on the board
~IE: U11.7 (O3); also elsewhere on the board
~LD: U16.8; also elsewhere on the board
~OE: U11.5 (O1); also elsewhere on the board
~OL: U16.6; also elsewhere on the board
~PH: D4.1 (K), U16.11
~PL: D3.2 (A), D4.2 (A), R7.1; also elsewhere on the board
~WE: U16.3; also elsewhere on the board
~XL: U13.11 (O4); also elsewhere on the board
~YL: U13.10 (O5)

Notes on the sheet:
To program counter
JUMP
During write, AC and OUT are blocked from being written to by U16B and U16C. This way, all 5 memory addressing modes can be used in ST instructions.
To user registers
[Y,X],AC
Buffer / Octal inverter
16-bit jump (JMP) detector
From AC and ALU
To RAM
[D],Y
Condition decoder
To memory address unit
Operation decoder
The control unit has: - 11 input signals: IR0:7, AC7, CO, CLK1 - The output comprises 19 control signals: /DE /OE /AE /IE AR0:3 AL /LD /XL /YL /OL IX EH EL /PL /PH /WE
To ALU
XOR
ADD
[D],OUT
STORE
Bus access decoder
[D],X
XXX breakdown symbol into 8 inverter gates
From instruction register
AND
SUB
To BUS and RAM
[Y,D],AC
LOAD
Mode decoder
[D],AC
[Y,X++],OUT
[X],AC
Wired AND

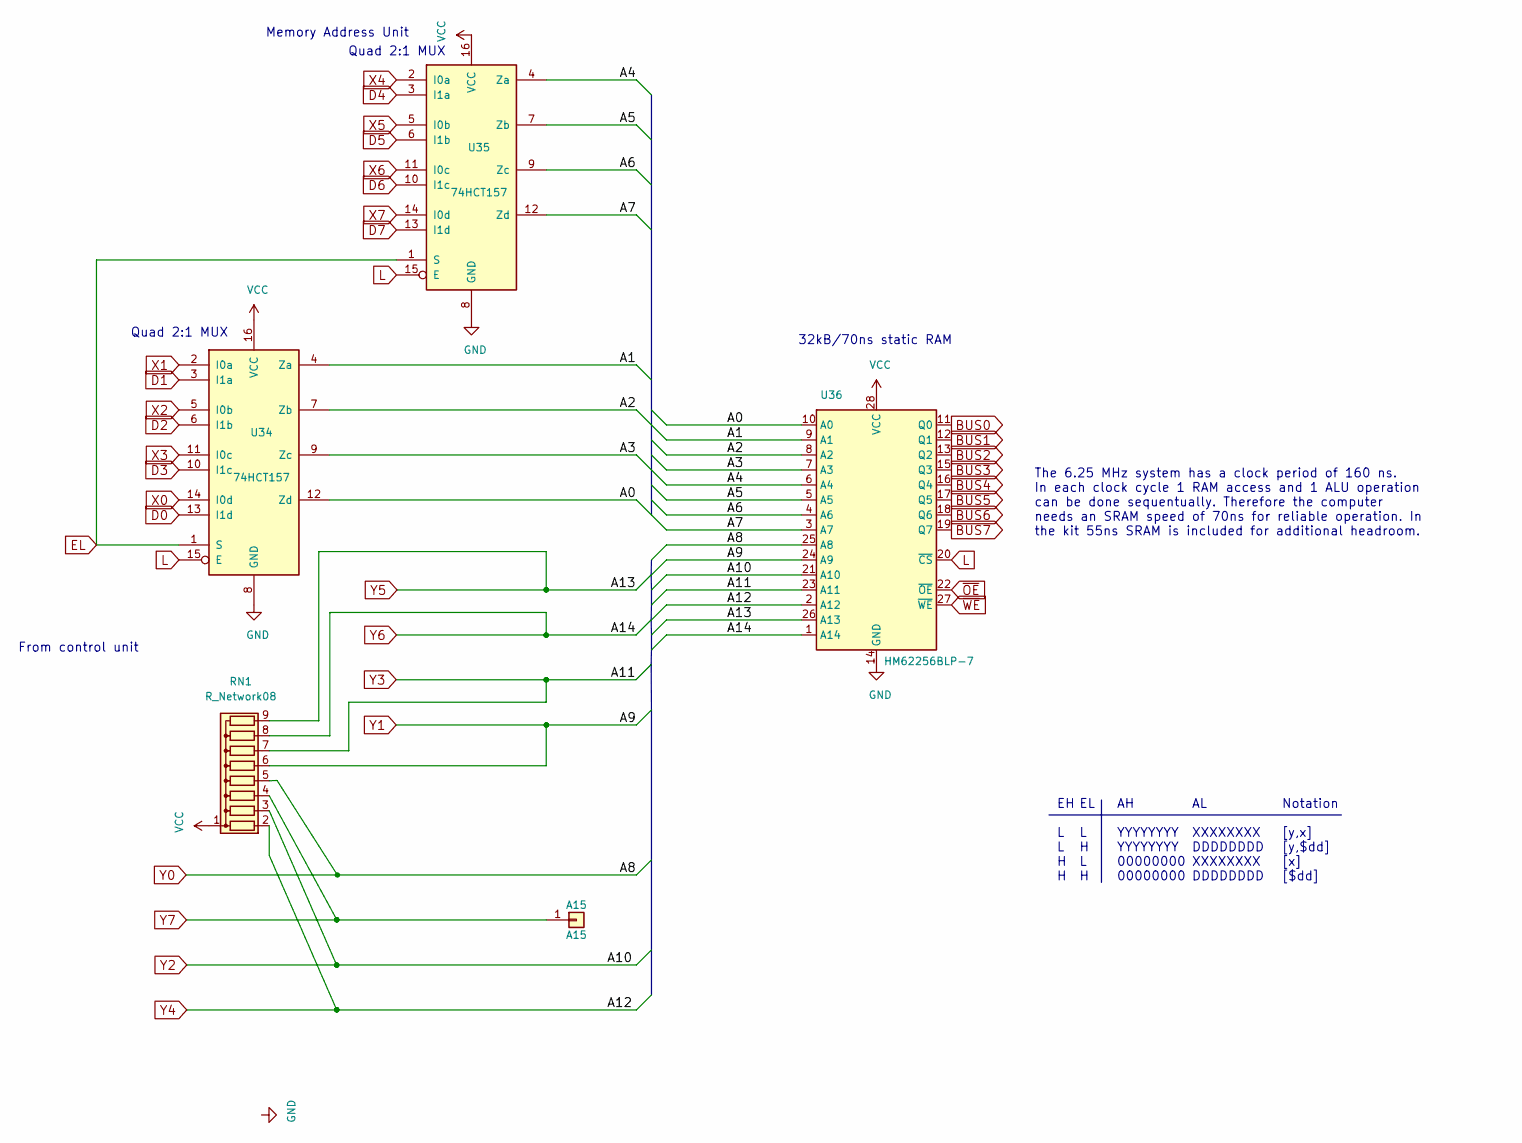
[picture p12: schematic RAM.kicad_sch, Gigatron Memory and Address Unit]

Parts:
A15: A15; TestPoint_THTPad_D2.0mm_Drill1.0mm
RN1: R_Network08; R_Array_SIP9
U34, U35: 74HCT157; DIP-16_W7.62mm
U36: HM62256BLP-7; DIP-28_W15.24mm

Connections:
/RAM/A0: U34.12 (Zd), U36.10 (A0)
/RAM/A1: U34.4 (Za), U36.9 (A1)
/RAM/A2: U34.7 (Zb), U36.8 (A2)
/RAM/A3: U34.9 (Zc), U36.7 (A3)
/RAM/A4: U35.4 (Za), U36.6 (A4)
/RAM/A5: U35.7 (Zb), U36.5 (A5)
/RAM/A6: U35.9 (Zc), U36.4 (A6)
/RAM/A7: U35.12 (Zd), U36.3 (A7)
BUS0: U36.11 (Q0); also elsewhere on the board
BUS1: U36.12 (Q1); also elsewhere on the board
BUS2: U36.13 (Q2); also elsewhere on the board
BUS3: U36.15 (Q3); also elsewhere on the board
BUS4: U36.16 (Q4); also elsewhere on the board
BUS5: U36.17 (Q5); also elsewhere on the board
BUS6: U36.18 (Q6); also elsewhere on the board
BUS7: U36.19 (Q7); also elsewhere on the board
D0: U34.13 (I1d); also elsewhere on the board
D1: U34.3 (I1a); also elsewhere on the board
D2: U34.6 (I1b); also elsewhere on the board
D3: U34.10 (I1c); also elsewhere on the board
D4: U35.3 (I1a); also elsewhere on the board
D5: U35.6 (I1b); also elsewhere on the board
D6: U35.10 (I1c); also elsewhere on the board
D7: U35.13 (I1d); also elsewhere on the board
EL: U34.1 (S), U35.1 (S); also elsewhere on the board
GND: U34.8 (GND), U35.8 (GND), U36.14 (GND); also elsewhere on the board
L: U34.15 (E), U35.15 (E), U36.20 (~CS); also elsewhere on the board
VCC: RN1.1 (common), U34.16 (VCC), U35.16 (VCC), U36.28 (VCC); also elsewhere on the board
X0: U34.14 (I0d); also elsewhere on the board
X1: U34.2 (I0a); also elsewhere on the board
X2: U34.5 (I0b); also elsewhere on the board
X3: U34.11 (I0c); also elsewhere on the board
X4: U35.2 (I0a); also elsewhere on the board
X5: U35.5 (I0b); also elsewhere on the board
X6: U35.11 (I0c); also elsewhere on the board
X7: U35.14 (I0d); also elsewhere on the board
Y0: RN1.5 (R4), U36.25 (A8); also elsewhere on the board
Y1: RN1.6 (R5), U36.24 (A9); also elsewhere on the board
Y2: RN1.3 (R2), U36.21 (A10); also elsewhere on the board
Y3: U36.23 (A11); also elsewhere on the board
Y4: RN1.2 (R1), U36.2 (A12); also elsewhere on the board
Y5: RN1.9 (R8), U36.26 (A13); also elsewhere on the board
Y6: RN1.8 (R7), U36.1 (A14); also elsewhere on the board
Y7: A15.1, RN1.4 (R3); also elsewhere on the board
~OE: U36.22 (~OE); also elsewhere on the board
~WE: U36.27 (~WE); also elsewhere on the board

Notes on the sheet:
From control unit
AH YYYYYYYY YYYYYYYY 00000000 00000000
The 6.25 MHz system has a clock period of 160 ns. In each clock cycle 1 RAM access and 1 ALU operation can be done sequentually. Therefore the computer needs an SRAM speed of 70ns for reliable operation. In the kit 55ns SRAM is included for additional headroom.
Quad 2:1 MUX
EH L L H H
AL XXXXXXXX DDDDDDDD XXXXXXXX DDDDDDDD
EL L H L H
32kB/70ns static RAM
Notation [y,x] [y,$dd] [x] [$dd]
Memory Address Unit

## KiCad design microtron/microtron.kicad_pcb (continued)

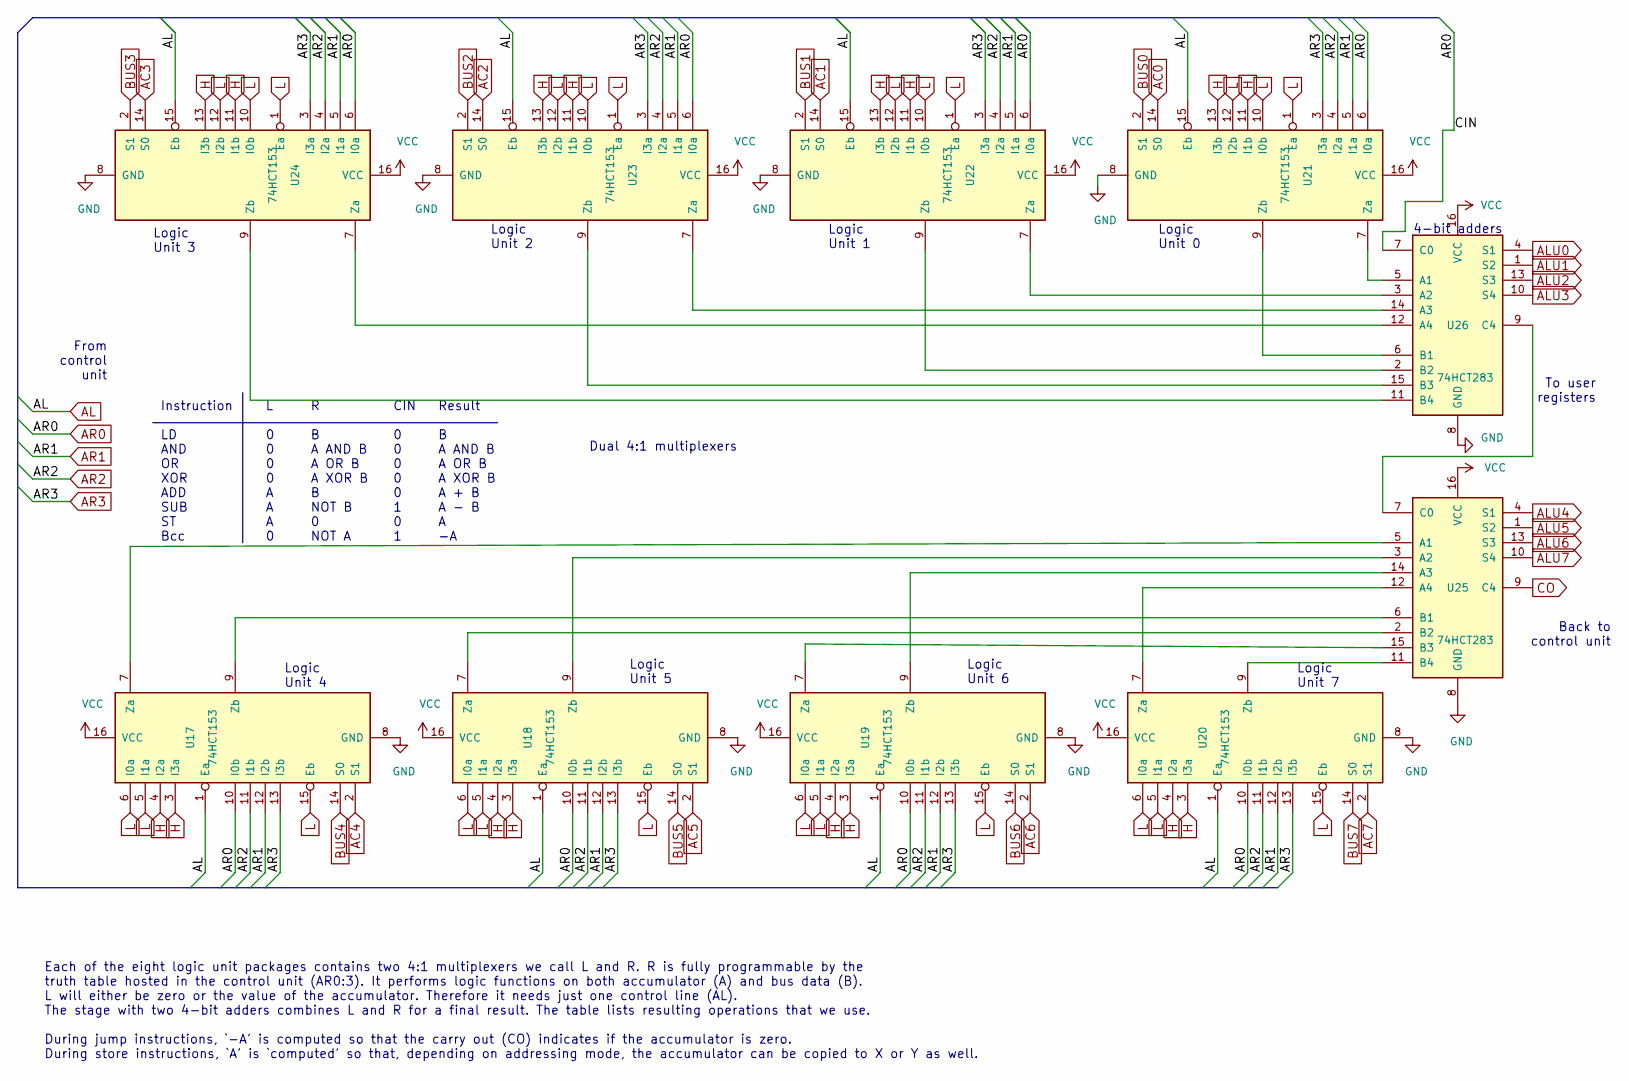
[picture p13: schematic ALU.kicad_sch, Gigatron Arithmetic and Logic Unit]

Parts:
U17, U18, U19, U20, U21, U22, U23, U24: 74HCT153; DIP-16_W7.62mm
U25, U26: 74HCT283; DIP-16_W7.62mm

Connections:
AC0: U21.14 (S0); also elsewhere on the board
AC1: U22.14 (S0); also elsewhere on the board
AC2: U23.14 (S0); also elsewhere on the board
AC3: U24.14 (S0); also elsewhere on the board
AC4: U17.2 (S1); also elsewhere on the board
AC5: U18.2 (S1); also elsewhere on the board
AC6: U19.2 (S1); also elsewhere on the board
AC7: U20.2 (S1); also elsewhere on the board
AL: U17.1 (Ea), U18.1 (Ea), U19.1 (Ea), U20.1 (Ea), U21.15 (Eb), U22.15 (Eb), U23.15 (Eb), U24.15 (Eb); also elsewhere on the board
ALU0: U26.4 (S1); also elsewhere on the board
ALU1: U26.1 (S2); also elsewhere on the board
ALU2: U26.13 (S3); also elsewhere on the board
ALU3: U26.10 (S4); also elsewhere on the board
ALU4: U25.4 (S1); also elsewhere on the board
ALU5: U25.1 (S2); also elsewhere on the board
ALU6: U25.13 (S3); also elsewhere on the board
ALU7: U25.10 (S4); also elsewhere on the board
AR0: U17.10 (I0b), U18.10 (I0b), U19.10 (I0b), U20.10 (I0b), U21.6 (I0a), U22.6 (I0a), U23.6 (I0a), U24.6 (I0a), U26.7 (C0); also elsewhere on the board
AR1: U17.12 (I2b), U18.12 (I2b), U19.12 (I2b), U20.12 (I2b), U21.5 (I1a), U22.5 (I1a), U23.5 (I1a), U24.5 (I1a); also elsewhere on the board
AR2: U17.11 (I1b), U18.11 (I1b), U19.11 (I1b), U20.11 (I1b), U21.4 (I2a), U22.4 (I2a), U23.4 (I2a), U24.4 (I2a); also elsewhere on the board
AR3: U17.13 (I3b), U18.13 (I3b), U19.13 (I3b), U20.13 (I3b), U21.3 (I3a), U22.3 (I3a), U23.3 (I3a), U24.3 (I3a); also elsewhere on the board
BUS0: U21.2 (S1); also elsewhere on the board
BUS1: U22.2 (S1); also elsewhere on the board
BUS2: U23.2 (S1); also elsewhere on the board
BUS3: U24.2 (S1); also elsewhere on the board
BUS4: U17.14 (S0); also elsewhere on the board
BUS5: U18.14 (S0); also elsewhere on the board
BUS6: U19.14 (S0); also elsewhere on the board
BUS7: U20.14 (S0); also elsewhere on the board
CO: U25.9 (C4); also elsewhere on the board
GND: U17.8 (GND), U18.8 (GND), U19.8 (GND), U20.8 (GND), U21.8 (GND), U22.8 (GND), U23.8 (GND), U24.8 (GND), U25.8 (GND), U26.8 (GND); also elsewhere on the board
H: U17.3 (I3a), U17.4 (I2a), U18.3 (I3a), U18.4 (I2a), U19.3 (I3a), U19.4 (I2a), U20.3 (I3a), U20.4 (I2a), U21.11 (I1b), U21.13 (I3b), U22.11 (I1b), U22.13 (I3b), U23.11 (I1b), U23.13 (I3b), U24.11 (I1b), U24.13 (I3b); also elsewhere on the board
L: U17.5 (I1a), U17.6 (I0a), U17.15 (Eb), U18.5 (I1a), U18.6 (I0a), U18.15 (Eb), U19.5 (I1a), U19.6 (I0a), U19.15 (Eb), U20.5 (I1a), U20.6 (I0a), U20.15 (Eb), U21.1 (Ea), U21.10 (I0b), U21.12 (I2b), U22.1 (Ea), U22.10 (I0b), U22.12 (I2b), U23.1 (Ea), U23.10 (I0b), U23.12 (I2b), U24.1 (Ea), U24.10 (I0b), U24.12 (I2b); also elsewhere on the board
unnamed: U17.7 (Za), U25.5 (A1)
unnamed: U17.9 (Zb), U25.6 (B1)
unnamed: U18.7 (Za), U25.2 (B2)
unnamed: U18.9 (Zb), U25.3 (A2)
unnamed: U19.7 (Za), U25.15 (B3)
unnamed: U19.9 (Zb), U25.14 (A3)
unnamed: U20.7 (Za), U25.12 (A4)
unnamed: U20.9 (Zb), U25.11 (B4)
unnamed: U21.7 (Za), U26.5 (A1)
unnamed: U21.9 (Zb), U26.6 (B1)
unnamed: U22.7 (Za), U26.3 (A2)
unnamed: U22.9 (Zb), U26.2 (B2)
unnamed: U23.7 (Za), U26.14 (A3)
unnamed: U23.9 (Zb), U26.15 (B3)
unnamed: U24.7 (Za), U26.12 (A4)
unnamed: U24.9 (Zb), U26.11 (B4)
unnamed: U25.7 (C0), U26.9 (C4)
VCC: U17.16 (VCC), U18.16 (VCC), U19.16 (VCC), U20.16 (VCC), U21.16 (VCC), U22.16 (VCC), U23.16 (VCC), U24.16 (VCC), U25.16 (VCC), U26.16 (VCC); also elsewhere on the board

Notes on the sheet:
Logic Unit 7
Back to control unit
Logic Unit 1
Logic Unit 0
Dual 4:1 multiplexers
Result B A AND B A OR B A XOR B A + B A - B A -A
Logic Unit 6
Logic Unit 2
From control unit
Instruction LD AND OR XOR ADD SUB ST Bcc
R B A AND B A OR B A XOR B B NOT B 0 NOT A
CIN 0 0 0 0 0 1 0 1
Logic Unit 4
Each of the eight logic unit packages contains two 4:1 multiplexers we call L and R. R is fully programmable by the truth table hosted in the control unit (AR0:3). It performs logic functions on both accumulator (A) and bus data (B). L will either be zero or the value of the accumulator. Therefore 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
To user registers
L 0 0 0 0 A A A 0
Logic Unit 5
4-bit adders
Logic Unit 3

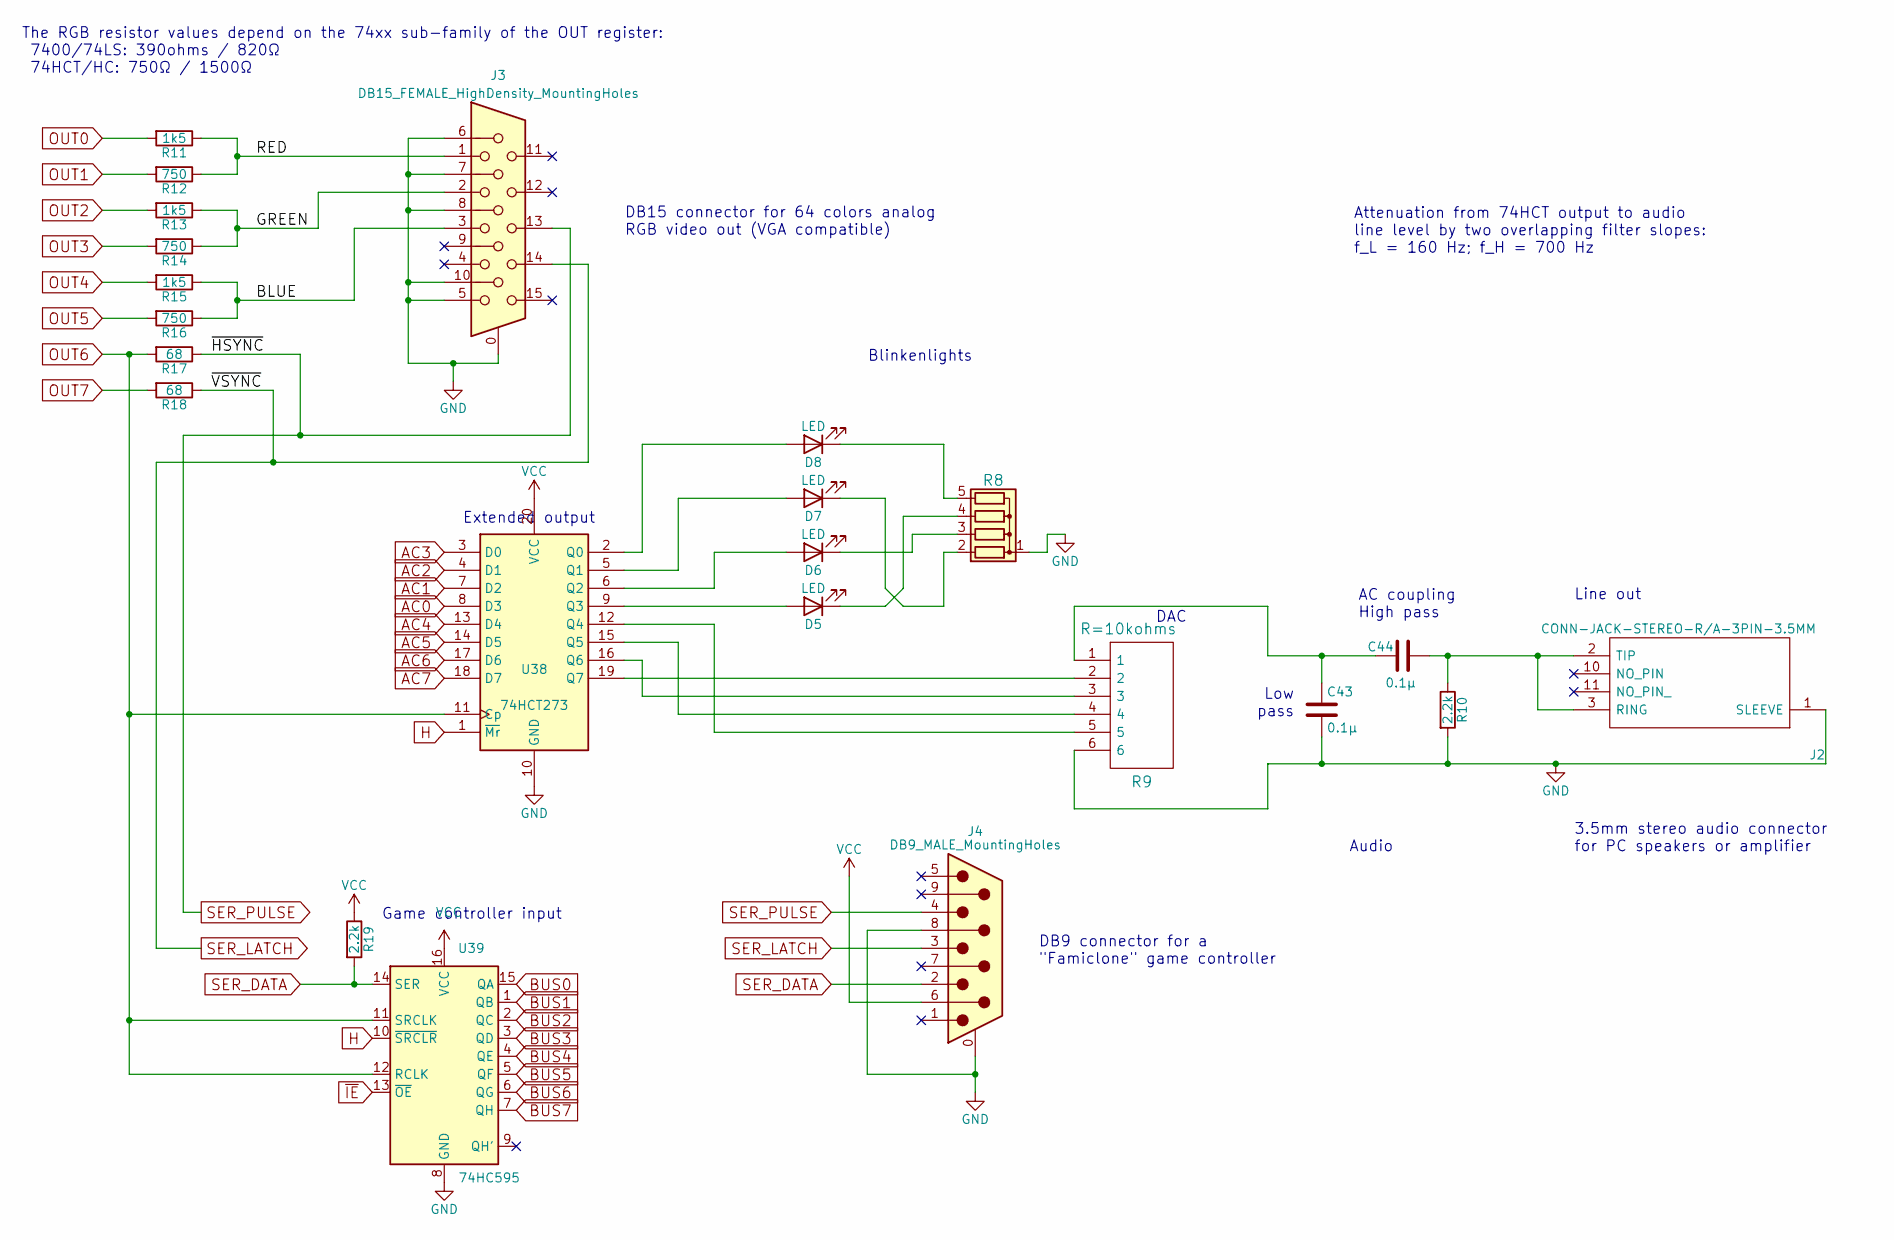
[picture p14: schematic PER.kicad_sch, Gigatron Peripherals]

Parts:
C43, C44: 0.1µ; C_Disc_D4.3mm_W1.9mm_P5.00mm
D5, D6, D7, D8: LED; LED_D3.0mm
J2: CONN-JACK-STEREO-R/A-3PIN-3.5MM; SJ13523N
J3: DB15_FEMALE_HighDensity_MountingHoles; DSUB-15-HD_Female_Horizontal_P2.29x1.98mm_EdgePinOffset3.03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
J4: DB9_MALE_MountingHoles; DSUB-9_Female_Horizontal_P2.77x2.84mm_EdgePinOffset4.94mm_H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
R8: 4605X-101-222LF; R_Array_SIP5
R9: R=10kohms; R_Array_SIP6
R10, R19: 2.2k; R_Axial_DIN0207_L6.3mm_D2.5mm_P10.16mm_Horizontal
R11, R13, R15: 1k5; R_Axial_DIN0207_L6.3mm_D2.5mm_P10.16mm_Horizontal
R12, R14, R16: 750; R_Axial_DIN0207_L6.3mm_D2.5mm_P10.16mm_Horizontal
R17, R18: 68; R_Axial_DIN0207_L6.3mm_D2.5mm_P10.16mm_Horizontal
U38: 74HCT273; DIP-20_W7.62mm
U39: 74HC595; DIP-16_W7.62mm

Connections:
/PER/BLUE: J3.3, R15.1, R16.1
/PER/GREEN: J3.2, R13.1, R14.1
/PER/RED: J3.1, R11.1, R12.1
AC0: U38.8 (D3); also elsewhere on the board
AC1: U38.7 (D2); also elsewhere on the board
AC2: U38.4 (D1); also elsewhere on the board
AC3: U38.3 (D0); also elsewhere on the board
AC4: U38.13 (D4); also elsewhere on the board
AC5: U38.14 (D5); also elsewhere on the board
AC6: U38.17 (D6); also elsewhere on the board
AC7: U38.18 (D7); also elsewhere on the board
BUS0: U39.15 (QA); also elsewhere on the board
BUS1: U39.1 (QB); also elsewhere on the board
BUS2: U39.2 (QC); also elsewhere on the board
BUS3: U39.3 (QD); also elsewhere on the board
BUS4: U39.4 (QE); also elsewhere on the board
BUS5: U39.5 (QF); also elsewhere on the board
BUS6: U39.6 (QG); also elsewhere on the board
BUS7: U39.7 (QH); also elsewhere on the board
GND: C43.2, J2.1 (SLEEVE), J3.0, J3.5, J3.6, J3.7, J3.8, J3.10, J4.0 (PAD), J4.8, R8.1 (common), R9.6, R10.2, U38.10 (GND), U39.8 (GND); also elsewhere on the board
H: U38.1 (~Mr), U39.10 (~SRCLR); also elsewhere on the board
unnamed: C43.1, C44.2, R9.1
unnamed: C44.1, J2.2 (TIP), J2.3 (RING), R10.1
unnamed: D5.1 (K), R8.4 (R3)
unnamed: D5.2 (A), U38.9 (Q3)
unnamed: D6.1 (K), R8.3 (R2)
unnamed: D6.2 (A), U38.6 (Q2)
unnamed: D7.1 (K), R8.2 (R1)
unnamed: D7.2 (A), U38.5 (Q1)
unnamed: D8.1 (K), R8.5 (R4)
unnamed: D8.2 (A), U38.2 (Q0)
unnamed: R9.2, U38.19 (Q7)
unnamed: R9.3, U38.16 (Q6)
unnamed: R9.4, U38.15 (Q5)
unnamed: R9.5, U38.12 (Q4)
OUT0: R11.2; also elsewhere on the board
OUT1: R12.2; also elsewhere on the board
OUT2: R13.2; also elsewhere on the board
OUT3: R14.2; also elsewhere on the board
OUT4: R15.2; also elsewhere on the board
OUT5: R16.2; also elsewhere on the board
OUT6: R17.2, U38.11 (Cp), U39.11 (SRCLK), U39.12 (RCLK); also elsewhere on the board
OUT7: R18.2; also elsewhere on the board
SER_DATA: J4.2, R19.2, U39.14 (SER)
SER_LATCH: J3.14, J4.3, R18.1
SER_PULSE: J3.13, J4.4, R17.1
VCC: J4.6, R19.1, U38.20 (VCC), U39.16 (VCC); also elsewhere on the board
~IE: U39.13 (~OE); also elsewhere on the board

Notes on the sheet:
DB15 connector for 64 colors analog RGB video out (VGA compatible)
DAC
Blinkenlights
Game controller input
Attenuation from 74HCT output to audio line level by two overlapping filter slopes: f_L = 160 Hz; f_H = 700 Hz
The RGB resistor values depend on the 74xx sub-family of the OUT register: 7400/74LS: 390ohms / 820Ω 74HCT/HC: 750Ω / 1500Ω
Audio
3.5mm stereo audio connector for PC speakers or amplifier
AC coupling High pass
Low pass
DB9 connector for a "Famiclone" game controller
Line out
Extended output

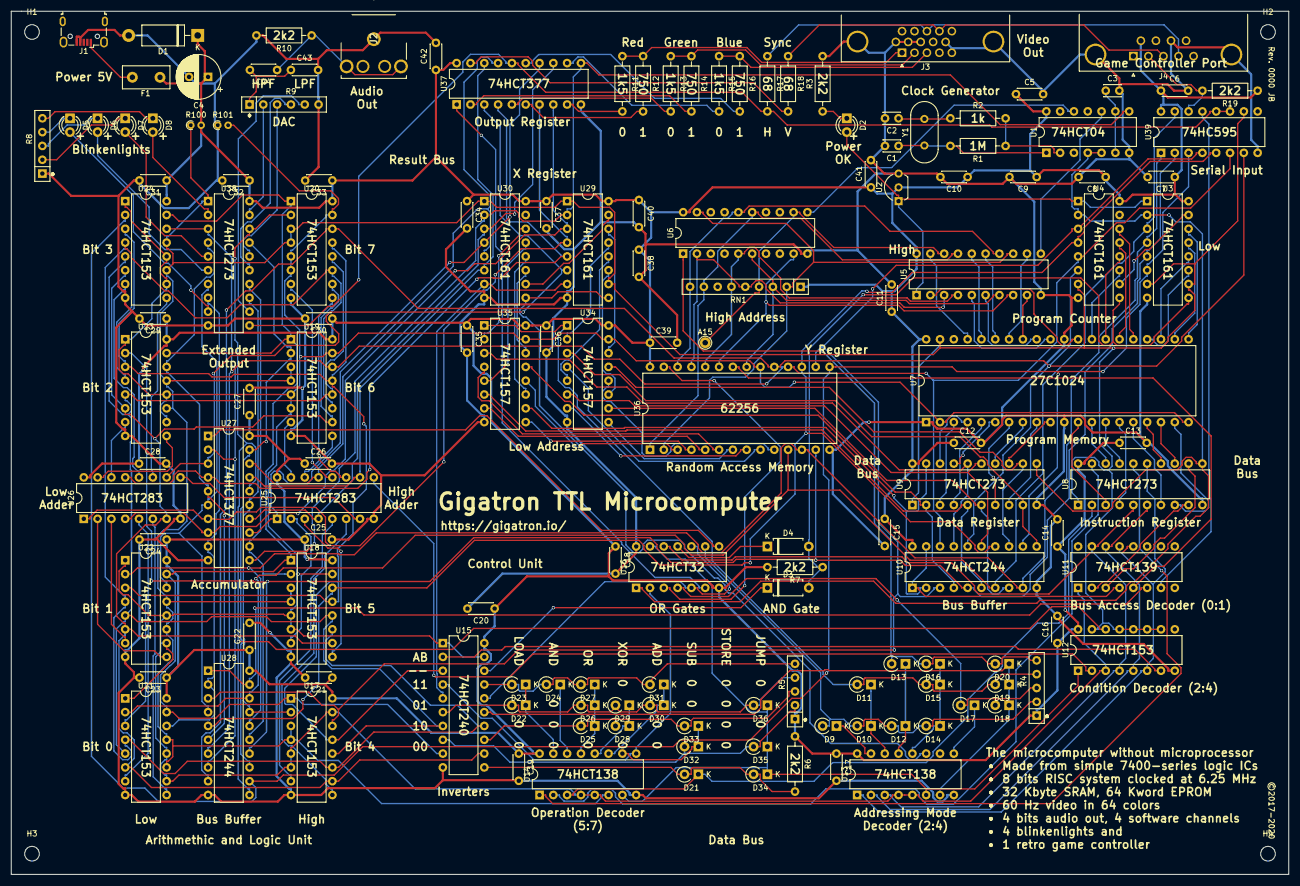
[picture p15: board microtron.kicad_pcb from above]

Board: 2 copper layers, 234.9 x 158.8 mm, 149 parts (0 on the bottom side), 202 nets.

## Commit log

2022-06-03 initial setup and replaced PCH in schematics
    [ALU-2020-07-15-16-13-58.sch, ALU.kicad_sch, ALU.sch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]
2022-06-03 removed Y multiplexers
    [ALU-2020-07-15-16-13-58.sch, ALU.kicad_sch, ALU.sch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]
2022-07-18 removed PCH incrementer and routed PCB
    [REG.kicad_sch, microtron.dsn, microtron.kicad_pcb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]

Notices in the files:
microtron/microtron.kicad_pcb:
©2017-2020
